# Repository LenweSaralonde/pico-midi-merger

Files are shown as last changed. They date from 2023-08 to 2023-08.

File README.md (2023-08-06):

# 8-port MIDI merger using Raspberry Pi Pico

Low latency 8-port MIDI merger based on a [Raspberry Pi Pico](https://www.raspberrypi.com/products/raspberry-pi-pico/).

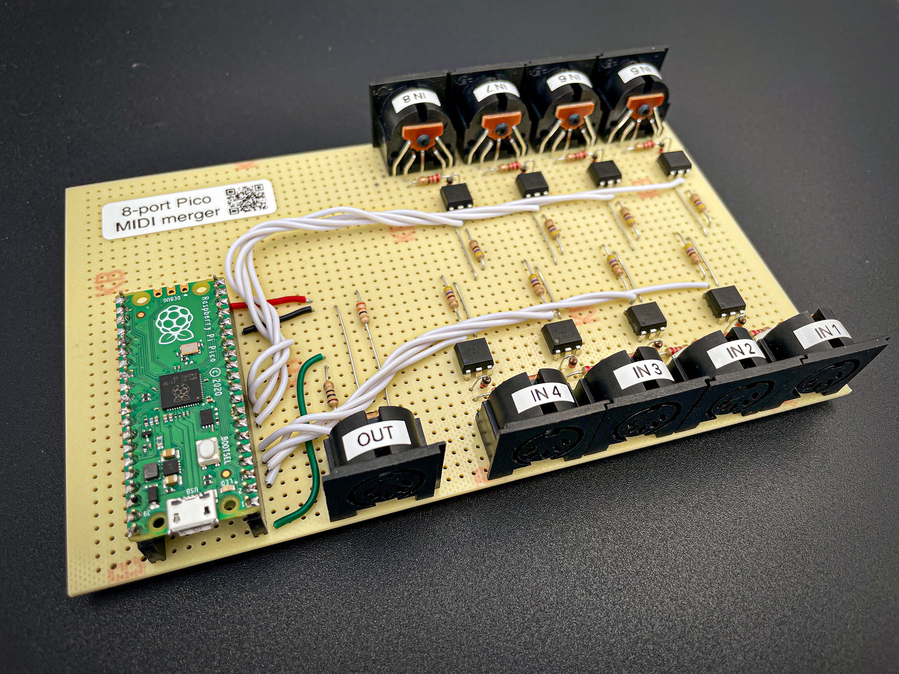
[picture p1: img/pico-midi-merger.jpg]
8-port Pico MIDI merger


## Schematic

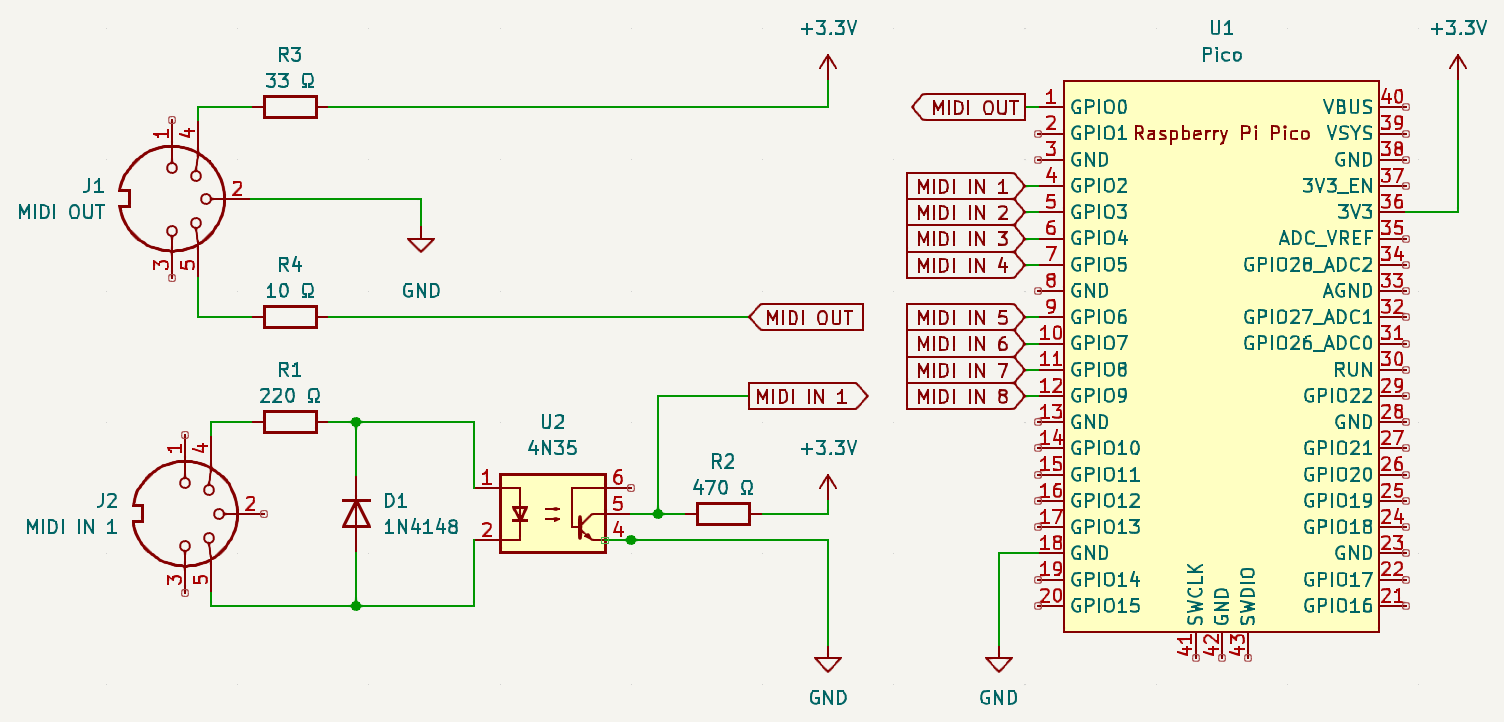
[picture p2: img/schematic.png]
8-port Pico MIDI merger schematic


The circuit consists in 8 standard MIDI inputs and 1 MIDI output, rated for 3.3V.

It's powered by the Raspberry Pi Pico via USB that provides 3.3V. MIDI IN 1-8 are connected to GPIO2-9. MIDI OUT is connected to UART0 TX (GPIO0).

The MIDI inputs are built around the 4N35 optocoupler. Other MIDI input designs for the Raspberry Pi Pico that use other optocoupler references would work as well.

## Build

The circuit can be built on a zero PCB or a breadboard.

8-port Pico MIDI merger zero PCB layout

Components list:
* 1x Raspberry Pi Pico
* 2x 20-pin PCB connectors
* 9x 180° DIN sockets
* 8x 4N35 optocouplers
* 8x 1N4148 diodes
* 8x 220 ohm resistors
* 8x 470 ohm resistors
* 1x 33 ohm resistor
* 1x 10 ohm resistor

## Implementation

The 8-port merger code is written in C++ using [SerialPIO](https://arduino-pico.readthedocs.io/en/latest/piouart.html). Working directly at the serial level instead of using a MIDI library allows to achieve the lowest latency possible by routing the incoming MIDI messages directly to the output since the first byte and to properly handle interleaved real-time messages.

## Merging rules

The merging rules are based on the [MERGE-8 by Kenton UK](https://kentonuk.com/product/merge-8/).

### MIDI Clock

When power is first applied, no input is defined as a master and all clock messages from all inputs will be passed until one input is defined as a master.

The most recent input to receive a START command (or Song Position Pointer=0 followed by CONTINUE) will become the clock master.

That input continues to be the clock master until another input satisfies the above condition.

### Active Sensing

The first input to receive an Active Sensing message will become the Active Sensing master. Active sensing messages from that input will be passed to the output, any active sensing messages received at other inputs will be ignored. An input will stay as Active Sensing master until no more Active Sensing messages are received at that input for a period of around 5 seconds. Then another input has the opportunity to become the Active Sensing master.

### SysEx Messages

While any input is handling a SysEx message it becomes the SysEx master, and SysEx messages from all other inputs will be locked out until the message at the master input has finished.

SysEx messages may be terminated either with an End Of SysEx command (F7) or with any other status command.

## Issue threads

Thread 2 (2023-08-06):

Interleave any real-time message from other inputs during a SysEx message

LenweSaralonde, 2023-08-06:
While a SysEx message is being rerouted from an input, real-time messages from all inputs can be interleaved with the SysEx message.

However, this only works for real-time messages that are at the first position in their input buffer because the `next()` function only allows to know the first byte of the buffer before it's actually read. If non-real-time messages are pending in some other input buffers, any upcoming real-time messages from such input would be stuck until the SysEx message has ended.

In addition to the `next()` function, we may implement a FIFO structure that allows to pass the real time messages from other inputs, while keeping other message types on hold until the SysEx sequence of the current input has ended. Such structure could be a circular buffer with a start and an end indexes but also allowing "holes" (-1) that correspond to real-time messages that would have been read/extracted prior to other message types.

Closed 2023-08-23.

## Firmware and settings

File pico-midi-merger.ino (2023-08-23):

/*
 * 8-port MIDI Merger for Raspberry Pi Pico
 */

// Using UART0 TX for MIDI Out

// MIDI input GPIO pins numbers
#define GP_IN_0 2  // Physical pin 4
#define GP_IN_1 3  // Physical pin 5
#define GP_IN_2 4  // Physical pin 6
#define GP_IN_3 5  // Physical pin 7
#define GP_IN_4 6  // Physical pin 9
#define GP_IN_5 7  // Physical pin 10
#define GP_IN_6 8  // Physical pin 11
#define GP_IN_7 9  // Physical pin 12

// FIFO size
#define FIFO_SIZE 256

// MIDI baud rate
#define MIDI_BAUD_RATE 31250

// MIDI receive timeout in microseconds
#define MIDI_RECEIVE_TIMEOUT 640

// Duration in microseconds the activity LED remains on after sending a data byte
#define ACTIVITY_LED_DURATION 320

// Active sensing timeout in ms
#define ACTIVE_SENSING_TIMEOUT 5000

// Number of input ports
#define NUM_INPUT_PORTS 8

// Undefined port number
#define PORT_NONE 255

// Create input serial ports
SerialPIO SerialPIO0(SerialPIO::NOPIN, GP_IN_0, FIFO_SIZE);
SerialPIO SerialPIO1(SerialPIO::NOPIN, GP_IN_1, FIFO_SIZE);
SerialPIO SerialPIO2(SerialPIO::NOPIN, GP_IN_2, FIFO_SIZE);
SerialPIO SerialPIO3(SerialPIO::NOPIN, GP_IN_3, FIFO_SIZE);
SerialPIO SerialPIO4(SerialPIO::NOPIN, GP_IN_4, FIFO_SIZE);
SerialPIO SerialPIO5(SerialPIO::NOPIN, GP_IN_5, FIFO_SIZE);
SerialPIO SerialPIO6(SerialPIO::NOPIN, GP_IN_6, FIFO_SIZE);
SerialPIO SerialPIO7(SerialPIO::NOPIN, GP_IN_7, FIFO_SIZE);

// FIFO buffers for each port
int buffer[NUM_INPUT_PORTS][FIFO_SIZE] = {};
int bufferStartIndex[NUM_INPUT_PORTS] = {};
int bufferSize[NUM_INPUT_PORTS] = {};

// Running statuses
uint8_t runningStatus[NUM_INPUT_PORTS] = {};

// Last sent MIDI message type
uint8_t lastSentStatusByte = 0x00;

// Activity LED is on or off
bool isActivityLedOn = false;

// Time in microseconds the last data byte was sent to MIDI out
unsigned long lastSentDataByteMicros;

// Master clock port number (0-7 or PORT_NONE)
uint8_t masterClockPort = PORT_NONE;

// Master active sensing port number (0-7 or PORT_NONE)
uint8_t activeSensingPort = PORT_NONE;

// Last time in ms the last active sensing message was received from the active sensing port
unsigned long lastReceivedActiveSensingMillis;

// Keep track of the song position bytes for each port
uint8_t songPosition[NUM_INPUT_PORTS][2] = {};

/**
 * Get the serial port instance for the port number
 * @param portNumber
 * @return SerialPIO instance
 */
SerialPIO& getPort(uint8_t portNumber) {
  switch (portNumber) {
    case 0: return SerialPIO0; break;
    case 1: return SerialPIO1; break;
    case 2: return SerialPIO2; break;
    case 3: return SerialPIO3; break;
    case 4: return SerialPIO4; break;
    case 5: return SerialPIO5; break;
    case 6: return SerialPIO6; break;
    case 7: return SerialPIO7; break;
    default: return SerialPIO0; break;
  }
}

/**
 * Read the MIDI data from the serial port and store it into the port buffer
 * @param portNumber
 */
void readMIDI(uint8_t portNumber) {
  int& startIndex = bufferStartIndex[portNumber];
  int& size = bufferSize[portNumber];

  // Adjust the start index and size to the first valid byte
  // in case some deleted bytes are encountered as the beginning of the buffer.
  while (size > 0 && buffer[portNumber][startIndex] == -1) {
    startIndex = (startIndex + 1) % FIFO_SIZE;
    size--;
  }

  // Read the incoming data from the serial port and store it into the FIFO buffer.
  while (getPort(portNumber).available() > 0) {
    int byte = getPort(portNumber).read();
    if (size < FIFO_SIZE - 1) {
      buffer[portNumber][(startIndex + size) % FIFO_SIZE] = byte;
      size++;
    }
  }
}

/**
 * Return the available bytes for the port number
 * @param portNumber
 * @return number of bytes in the buffer
 */
uint8_t available(uint8_t portNumber) {
  readMIDI(portNumber);
  return bufferSize[portNumber];
}

/**
 * Return the next data byte for the port number
 * @param portNumber
 * @return the next byte or -1 if none
 */
int next(uint8_t portNumber) {
  // The buffer is empty
  if (available(portNumber) == 0) {
    return -1;
  }
  return buffer[portNumber][bufferStartIndex[portNumber]];
}

/**
 * Read one data byte from the port number
 * @param portNumber
 * @return the read byte or -1 if none
 */
int read(uint8_t portNumber) {
  // The buffer is empty
  if (available(portNumber) == 0) {
    return -1;
  }

  // Get current start index and size
  int& startIndex = bufferStartIndex[portNumber];
  int& size = bufferSize[portNumber];

  // Read the byte
  int byte = buffer[portNumber][startIndex];

  // Update start index and size
  startIndex = (startIndex + 1) % FIFO_SIZE;
  size--;

  return byte;
}

/**
 * Time out the master active sensing port if no AS message has been received during the timeout period
 */
void handleActiveSensingTimeout() {
  if (activeSensingPort != PORT_NONE && millis() - lastReceivedActiveSensingMillis > ACTIVE_SENSING_TIMEOUT) {
    activeSensingPort = PORT_NONE;
  }
}

/**
 * Indicates if the data byte is a status byte
 * @param dataByte
 * @return is status byte
 */
bool isStatusByte(int dataByte) {
  return dataByte >= 0x80;
}

/**
 * Indicates if the status byte is for a channel message
 * @param statusByte
 * @return is channel message
 */
bool isChannelMessageType(int statusByte) {
  return statusByte >= 0x80 && statusByte <= 0xEF;
}

/**
 * Indicates if the status byte is for a real-time message
 * @param statusByte
 * @return is real-time
 */
bool isRealTimeMessageType(int statusByte) {
  return statusByte >= 0xF8;
}

/**
 * Indicates if the status byte is for a system exclusive message
 * @param statusByte
 * @return is system exclusive
 */
bool isSystemExclusive(int statusByte) {
  return statusByte == 0xF0 || statusByte == 0xF7;  // System Exclusive Start or System Exclusive End
}

/**
 * Get the MIDI message length in bytes, including the status byte.
 * @param statusByte
 * @return message length or 0 if it can't be determined (SysEx)
 */
uint8_t getMessageLength(uint8_t statusByte) {
  // 1 byte messages
  if (
    statusByte == 0xF4 ||  // (Undefined)
    statusByte == 0xF5 ||  // (Undefined)
    statusByte == 0xF6 ||  // TuneRequest
    statusByte == 0xF8 ||  // Clock
    statusByte == 0xF9 ||  // Tick
    statusByte == 0xFA ||  // Start
    statusByte == 0xFB ||  // Continue
    statusByte == 0xFC ||  // Stop
    statusByte == 0xFD ||  // (Undefined)
    statusByte == 0xFE ||  // ActiveSensing
    statusByte == 0xFF     // SystemReset)
  ) {
    return 1;
  }

  // 2 bytes messages
  if (
    statusByte >= 0xC0 && statusByte <= 0xCF ||  // ProgramChange
    statusByte >= 0xD0 && statusByte <= 0xDF ||  // AfterTouchChannel
    statusByte == 0xF1 ||                        // TimeCodeQuarterFrame
    statusByte == 0xF3                           // SongSelect
  ) {
    return 2;
  }

  // 3 bytes messages
  if (
    statusByte >= 0x90 && statusByte <= 0x9F ||  // NoteOn
    statusByte >= 0x80 && statusByte <= 0x8F ||  // NoteOff
    statusByte >= 0xA0 && statusByte <= 0xAF ||  // AfterTouchPoly
    statusByte >= 0xB0 && statusByte <= 0xBF ||  // ControlChange
    statusByte >= 0xE0 && statusByte <= 0xEF ||  // PitchBend
    statusByte == 0xF2                           // SongPosition
  ) {
    return 3;
  }

  // Undefined length
  return 0;
}

/**
 * Turn the activity LED off if the delay has expired.
 */
void handleLedOff() {
  if (isActivityLedOn && micros() - lastSentDataByteMicros > ACTIVITY_LED_DURATION) {
    isActivityLedOn = false;
    digitalWrite(LED_BUILTIN, LOW);
  }
}

/**
 * Send a data byte to MIDI out
 * @param dataByte
 */
void sendDataByte(uint8_t dataByte) {
  // Turn the activity LED on
  digitalWrite(LED_BUILTIN, HIGH);
  isActivityLedOn = true;
  // Send byte
  Serial1.write(dataByte);
  lastSentDataByteMicros = micros();
}

/**
 * Send status byte from provided port number to MIDI out, if applicable
 * @param statusByte
 * @param portNumber
 */
void sendStatusByte(uint8_t statusByte, uint8_t portNumber) {
  // Attempting to send a master clock message while not being the master clock
  if (statusByte == 0xF8 && portNumber != masterClockPort) {
    return;
  }

  // Attempting to send an active sensing while not being the master AS port
  if (statusByte == 0xFE && portNumber != activeSensingPort) {
    return;
  }

  // Do not send the status byte if there is an outgoing running status
  if (isChannelMessageType(statusByte) && statusByte == lastSentStatusByte) {
    return;
  }

  // Send status byte to MIDI out
  sendDataByte(statusByte);
  lastSentStatusByte = statusByte;
}

/**
 * Process real-time message to determine the master clock and/or master active sensing port
 * @param statusByte
 * @param portNumber
 */
void processRealTimeMessage(uint8_t statusByte, uint8_t portNumber) {
  // Song start or song continue with position set to 0 received: set port number as master clock
  if (statusByte == 0xFA || statusByte == 0xFB && songPosition[portNumber][0] == 0x00 && songPosition[portNumber][1] == 0x00) {
    masterClockPort = portNumber;
  }
  // Active sensing
  else if (statusByte == 0xFE) {
    // Set AS port if undefined
    if (activeSensingPort == PORT_NONE) {
      activeSensingPort = portNumber;
      lastReceivedActiveSensingMillis = millis();
    }
    // Otherwise, update the last encountered AS message timestamp
    else if (activeSensingPort == portNumber) {
      lastReceivedActiveSensingMillis = millis();
    }
  }
}

/**
 * Forward real-time messages pending from all the input ports,
 * regardless of their position in the queue
 */
void mergeRealTimeMessages() {
  for (uint8_t portNumber = 0; portNumber < NUM_INPUT_PORTS; portNumber++) {
    if (available(portNumber) > 0) {
      for (int index = 0; index < bufferSize[portNumber]; index++) {
        int bufferIndex = (index + bufferStartIndex[portNumber]) % FIFO_SIZE;
        int dataByte = buffer[portNumber][bufferIndex];
        if (isRealTimeMessageType(dataByte)) {
          sendStatusByte(dataByte, portNumber);
          buffer[portNumber][bufferIndex] = -1;  // "delete" the read byte
        }
      }
    }
  }
}

/**
 * Merge incoming MIDI message for provided port number
 * @param portNumber
 */
void mergeMIDI(uint8_t portNumber) {
  // Nothing to read here
  if (available(portNumber) == 0)
    return;

  // Determine the type of message based on the first data byte
  uint8_t nextByte = next(portNumber);

  // Get and send status byte
  uint8_t statusByte;

  // It's a proper status byte
  if (isStatusByte(nextByte)) {
    statusByte = read(portNumber);
    sendStatusByte(statusByte, portNumber);
    processRealTimeMessage(statusByte, portNumber);
  }
  // Check if we have a valid running status for this port,
  // in this case we're reading the first data byte
  else if (runningStatus[portNumber] != 0x00) {
    statusByte = runningStatus[portNumber];
    sendStatusByte(statusByte, portNumber);
  }
  // This is an error
  else {
    // Read all the junk bytes until a proper status byte is encountered to try again in the next loop
    while (available(portNumber) > 0 && !isStatusByte(next(portNumber))) {
      read(portNumber);
    }
    return;
  }

  // Determine the number of bytes left or if it's a SysEx
  uint8_t messageLength = getMessageLength(statusByte);
  bool isSysEx = isSystemExclusive(statusByte);
  uint8_t bytesLeft = (!isSysEx && messageLength > 1) ? messageLength - 1 : 0;

  // Store running status for channel messages
  if (isChannelMessageType(statusByte)) {
    runningStatus[portNumber] = statusByte;
  }
  // Reset running status
  else if (!isRealTimeMessageType(statusByte)) {
    runningStatus[portNumber] = 0x00;
  }

  // Forward the message data to MIDI out
  unsigned int lastReceivedTime = micros();
  while (bytesLeft > 0 || isSysEx) {
    // Handle timeout
    if (micros() - lastReceivedTime > MIDI_RECEIVE_TIMEOUT) {
      handleLedOff();
      return;
    }

    // Interleave real-time messages
    mergeRealTimeMessages();

    // There is some data to read
    uint8_t dataByte;
    if (available(portNumber) > 0) {

      // Terminate the current SysEx message if the next byte is a status byte
      nextByte = next(portNumber);
      if (isSysEx && isStatusByte(nextByte) && !isRealTimeMessageType(nextByte) && !isSystemExclusive(nextByte)) {
        handleLedOff();
        return;
      }

      // Read and forward data byte
      dataByte = read(portNumber);
      sendDataByte(dataByte);
      lastReceivedTime = micros();

      // If was not a real-time message
      if (!isRealTimeMessageType(dataByte)) {

        // Keep track of the song position to determine the master clock port
        if (statusByte == 0xF2) {
          if (bytesLeft == 2) {
            songPosition[portNumber][0] = dataByte;
          } else if (bytesLeft == 1) {
            songPosition[portNumber][1] = dataByte;
          }
        }

        // One byte less to read
        if (!isSysEx) {
          bytesLeft--;
        }
        // End of SysEx message
        else if (dataByte == 0xF7) {
          isSysEx = false;
        }
      } else {
        processRealTimeMessage(dataByte, portNumber);
      }
    } else {
      handleLedOff();
    }
  }
}

/**
 * Reset merger
 */
void reset() {
  digitalWrite(LED_BUILTIN, LOW);
  isActivityLedOn = false;
  lastSentStatusByte = 0x00;
  masterClockPort = PORT_NONE;
  activeSensingPort = PORT_NONE;
  for (uint8_t portNumber = 0; portNumber < NUM_INPUT_PORTS; portNumber++) {
    bufferStartIndex[portNumber] = 0;
    bufferSize[portNumber] = 0;
    runningStatus[portNumber] = 0x00;
    songPosition[portNumber][0] = 0xFF;
    songPosition[portNumber][1] = 0xFF;
  }
}

/**
 * Initialize
 */
void setup() {
  pinMode(LED_BUILTIN, OUTPUT);
  Serial1.begin(MIDI_BAUD_RATE);
  for (uint8_t portNumber = 0; portNumber < NUM_INPUT_PORTS; portNumber++) {
    getPort(portNumber).begin(MIDI_BAUD_RATE);
  }
  reset();
}

/**
 * Main loop
 */
void loop() {
  for (uint8_t portNumber = 0; portNumber < NUM_INPUT_PORTS; portNumber++) {
    mergeMIDI(portNumber);
  }
  handleActiveSensingTimeout();
  handleLedOff();
}

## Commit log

2023-07-31 Added active sensing, activity LED & master clock
2023-08-06 Added documentation, pictures and schematics
    [pico-midi-merger.kicad_sch]
2023-08-08 Added source PSD for the zero PCB layout
